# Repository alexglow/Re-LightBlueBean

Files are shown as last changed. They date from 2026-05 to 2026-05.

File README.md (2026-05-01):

# Re-LightBlueBean
Reviving [PunchThrough Design](https://punchthrough.com)'s [LightBlue Bean](https://punchthrough.com/bean), after the shutdown. Because this beautiful little Bluetooth board deserves to live :D  

I've written up a tutorial for Mac users on my [website page](https://alexglow.notion.site/Beanie-Bots-19a5bc4fe798809aa190db6e0d67d61d?source=copy_link), which will likely update far more often than this repo. As of May '26, feel free to hit me up on [Mastodon](https://chaos.social/@alexglow) or [Bluesky](https://bsky.app/profile/alexglow.bsky.social) for updates.

I'm especially interested in backing up the Bean+ files, if anyone has them – since I was mostly interested in the original Bean.

## Hardware files
When PunchThrough discontinued the LightBlue Bean and Bean+, they open-sourced the files. What you see here is the ones I grabbed for the former, as well as a file with some of their notes.

## Code examples
Unless otherwise noted, examples were written by the PunchThrough team and are in the public domain. This info should be in the files, but I'm trying to get some basic material up immediately, and then I'll double-check.

I'm planning to upload two versions: a backup of their originals, and new versions I've been able to compile and upload in 2026 (using the PlatformIO plugin in VSCode).

## Other resources
* Archived examples page: https://web.archive.org/web/20151220051847/http://legacy.punchthrough.com/bean/examples
* Archived getting-started page: https://web.archive.org/web/20160920033849/http://punchthrough.com/bean/guides/getting-started/intro
* My ancient tutorial on Hackster.io (2016): https://www.hackster.io/glowascii/lightblue-bean-arduino-basics-de7a94
* More LightBlue Bean & Bean+ projects on Hackster.io: https://www.hackster.io/punchthrough/projects

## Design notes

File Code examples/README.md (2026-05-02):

# Code examples for LightBlue Bean

### Tested LightBlue Bean demos
Some examples I've cobbled together from other sources – including my own old Hackster project(s) and example Arduino code.

### Original PunchThrough demos
Pulled from the original PunchThrough site (via the Internet Archive). I added the public-domain header, along with the exact URL each was pulled from. These will probably work, using [this updated process](https://alexglow.notion.site/Beanie-Bots-19a5bc4fe798809aa190db6e0d67d61d?source=copy_link), as long as you add **#include <Arduino.h>** at the top.

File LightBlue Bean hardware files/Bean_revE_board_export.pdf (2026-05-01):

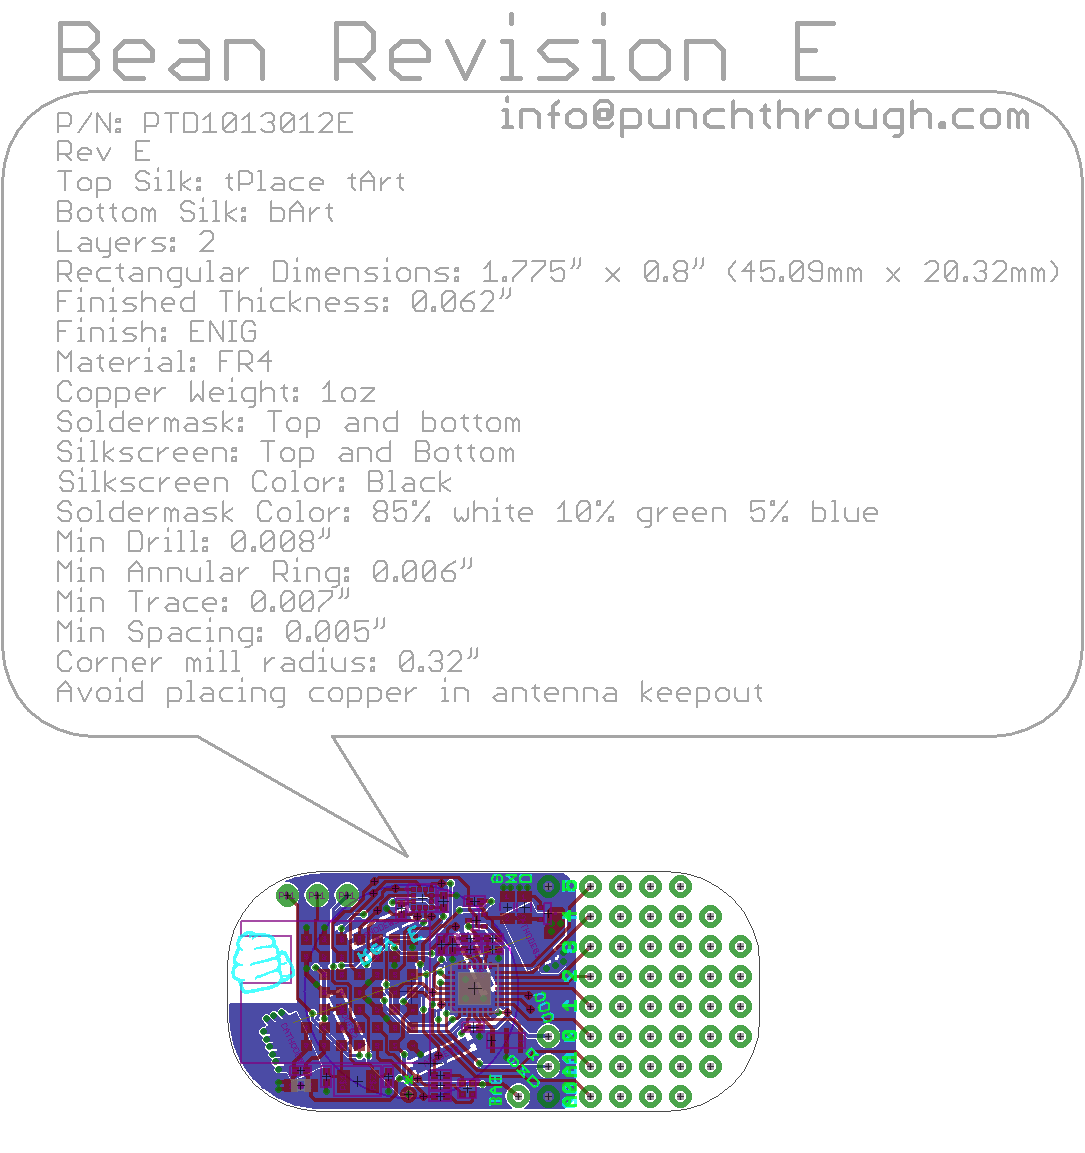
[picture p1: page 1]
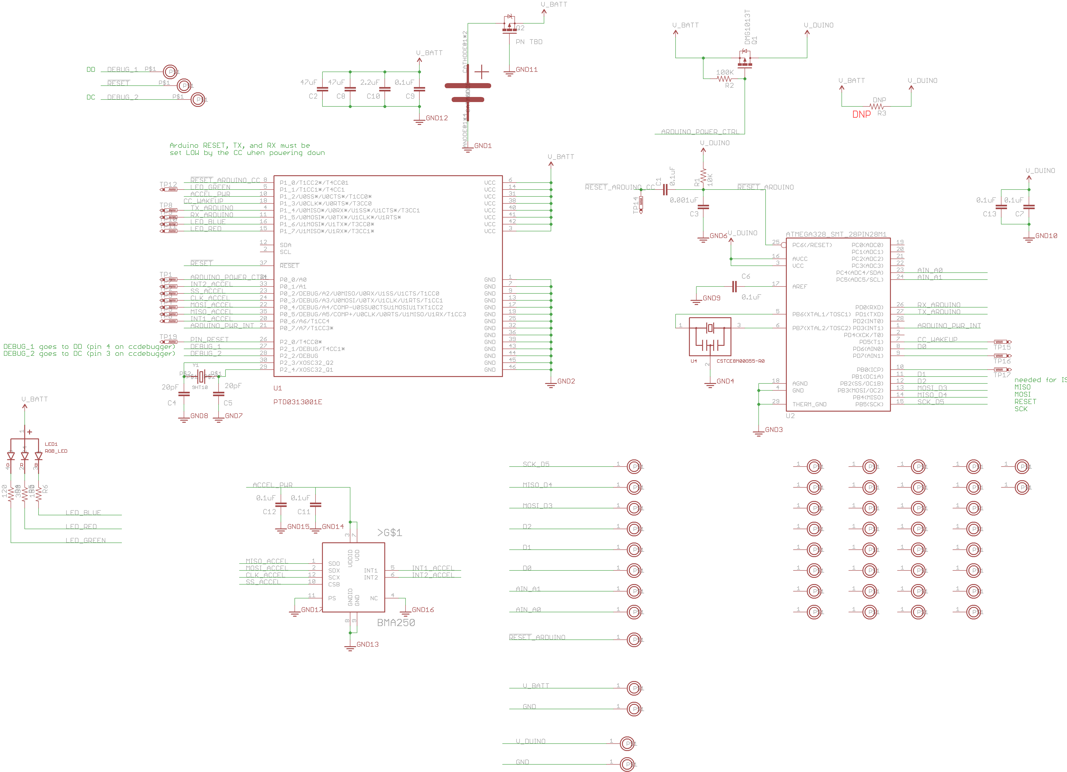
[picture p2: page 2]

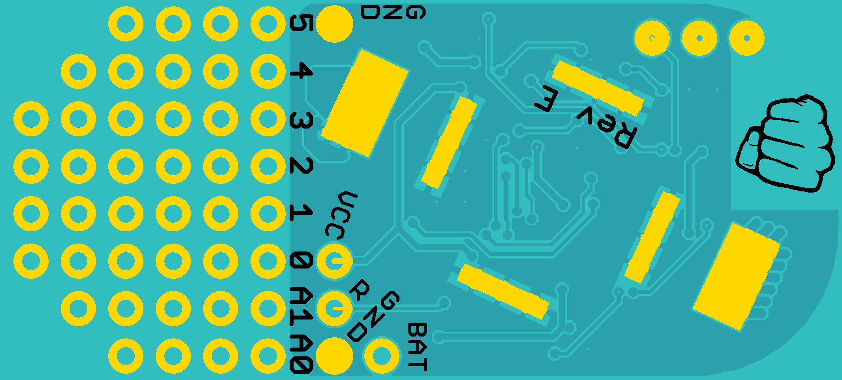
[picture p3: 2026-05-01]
LightBlue Bean hardware files/LightBlue Bean Rev E Board Files and 3D Model/3D Model/BEAN_MODEL_REVE_1.1.0/eagleUp_Bean_revE_bottom_board.png

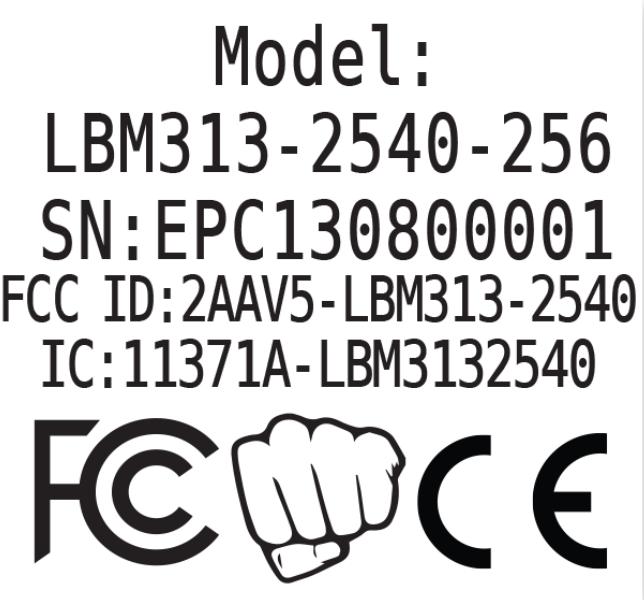
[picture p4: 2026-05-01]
LightBlue Bean hardware files/LightBlue Bean Rev E Board Files and 3D Model/3D Model/BEAN_MODEL_REVE_1.1.0/texture.png

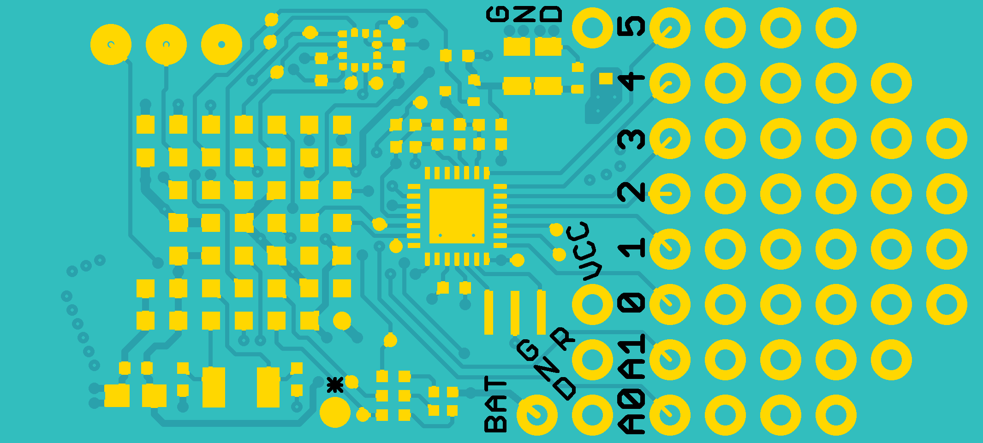
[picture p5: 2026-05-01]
LightBlue Bean hardware files/LightBlue Bean Rev E Board Files and 3D Model/3D Model/BEAN_MODEL_REVE_1.1.0/eagleUp_Bean_revE_top_board.png

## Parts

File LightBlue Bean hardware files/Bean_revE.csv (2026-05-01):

Part | Value | Device | Package | Description | TP_SIGNAL_NAME
C1 | 0.1uF | CAPACITOR_CERAMIC | 0402
C2 | 47uF | CAP0805 | 0805 | Capacitor
C3 | 0.001uF | CAPACITOR_CERAMIC | 0402
C4 | 20pF | CAPACITOR_CERAMIC | 0402
C5 | 20pF | CAPACITOR_CERAMIC | 0402
C6 | 0.1uF | CAPACITOR_CERAMIC | 0402
C7 | 0.1uF | CAPACITOR_CERAMIC | 0402
C8 | 47uF | CAP0805 | 0805 | Capacitor
C9 | 0.1uF | CAPACITOR_CERAMIC | 0402
C10 | 2.2uF | CAP0603-CAP | 0603-CAP | Capacitor
C11 | 0.1uF | CAPACITOR_CERAMIC | 0402
C12 | 0.1uF | CAPACITOR_CERAMIC | 0402
C13 | 0.1uF | CAPACITOR_CERAMIC | 0402
CN_BATT | CR20324_ELEVATED_PADS | CR20324_ELEVATED_PADS | BK-912-ALT
LED1 | RGB_LED | RGB_LED | SML-LX0404SIUPGUSB
Q1 | DMG1013T | MOSFET-PCHANNEL | SOT523 | Generic PMOSFET
Q2 | PN TBD | MOSFET-PCHANNEL | SOT523 | Generic PMOSFET
R1 | 10K | RESISTOR | 0402
R2 | 100K | RESISTOR | 0402
R3 | DNP | RESISTOR | 0402
R4 | 120 | RESISTOR | 0402
R5 | 390 | RESISTOR | 0402
R6 | 150 | RESISTOR | 0402
TP1 | PTR1TP06R | PTR1TP06R | TP06R | TEST PIN
TP2 | PTR1TP06R | PTR1TP06R | TP06R | TEST PIN
TP3 | PTR1TP06R | PTR1TP06R | TP06R | TEST PIN
TP4 | PTR1TP06R | PTR1TP06R | TP06R | TEST PIN
TP5 | PTR1TP06R | PTR1TP06R | TP06R | TEST PIN
TP6 | PTR1TP06R | PTR1TP06R | TP06R | TEST PIN
TP7 | PTR1TP06R | PTR1TP06R | TP06R | TEST PIN
TP8 | PTR1TP06R | PTR1TP06R | TP06R | TEST PIN
TP9 | PTR1TP06R | PTR1TP06R | TP06R | TEST PIN
TP10 | PTR1TP06R | PTR1TP06R | TP06R | TEST PIN
TP11 | PTR1TP06R | PTR1TP06R | TP06R | TEST PIN
TP12 | PTR1TP06R | PTR1TP06R | TP06R | TEST PIN
TP14 | PTR1TP06R | PTR1TP06R | TP06R | TEST PIN
TP15 | PTR1TP06R | PTR1TP06R | TP06R | TEST PIN
TP16 | PTR1TP06R | PTR1TP06R | TP06R | TEST PIN
TP17 | PTR1TP06R | PTR1TP06R | TP06R | TEST PIN
TP19 | PTR1TP14R | PTR1TP14R | TP14R | TEST PIN
U$1 | PROTO_POINT | PROTO_POINT | 1X01
U$3 | PROTO_POINT | PROTO_POINT | 1X01
U$4 | PROTO_POINT | PROTO_POINT | 1X01
U$5 | PROTO_POINT | PROTO_POINT | 1X01
U$6 | PROTO_POINT | PROTO_POINT | 1X01
U$7 | PROTO_POINT | PROTO_POINT | 1X01
U$8 | PROTO_POINT | PROTO_POINT | 1X01
U$9 | PROTO_POINT | PROTO_POINT | 1X01
U$10 | PROTO_POINT | PROTO_POINT | 1X01
U$11 | PROTO_POINT | PROTO_POINT | 1X01
U$12 | PROTO_POINT | PROTO_POINT | 1X01
U$13 | PROTO_POINT | PROTO_POINT | 1X01
U$14 | PROTO_POINT | PROTO_POINT | 1X01
U$15 | PROTO_POINT | PROTO_POINT | 1X01
U$16 | PROTO_POINT | PROTO_POINT | 1X01
U$17 | PROTO_POINT | PROTO_POINT | 1X01
U$18 | PROTO_POINT | PROTO_POINT | 1X01
U$19 | PROTO_POINT | PROTO_POINT | 1X01
U$20 | PROTO_POINT | PROTO_POINT | 1X01
U$21 | PROTO_POINT | PROTO_POINT | 1X01
U$22 | PROTO_POINT | PROTO_POINT | 1X01
U$23 | PROTO_POINT | PROTO_POINT | 1X01
U$24 | PROTO_POINT | PROTO_POINT | 1X01
U$25 | PROTO_POINT | PROTO_POINT | 1X01
U$26 | PROTO_POINT | PROTO_POINT | 1X01
U$27 | PROTO_POINT | PROTO_POINT | 1X01
U$28 | PROTO_POINT | PROTO_POINT | 1X01
U$29 | PROTO_POINT | PROTO_POINT | 1X01
U$30 | PROTO_POINT | PROTO_POINT | 1X01
U$31 | PROTO_POINT | PROTO_POINT | 1X01
U$32 | PROTO_POINT | PROTO_POINT | 1X01
U$33 | PROTO_POINT | PROTO_POINT | 1X01
U$34 | PROTO_POINT | PROTO_POINT | 1X01
U$35 | PROTO_POINT | PROTO_POINT | 1X01
U$36 | PROTO_POINT | PROTO_POINT | 1X01
U$37 | PROTO_POINT | PROTO_POINT | 1X01
U$38 | PROTO_POINT | PROTO_POINT | 1X01
U$39 | PROTO_POINT | PROTO_POINT | 1X01
U$40 | PROTO_POINT | PROTO_POINT | 1X01
U$41 | PROTO_POINT | PROTO_POINT | 1X01
U$42 | PROTO_POINT | PROTO_POINT | 1X01
U$43 | PROTO_POINT | PROTO_POINT | 1X01
U$44 | PROTO_POINT | PROTO_POINT | 1X01
U$45 | PROTO_POINT | PROTO_POINT | 1X01
U$46 | PROTO_POINT | PROTO_POINT | 1X01
U$49 | BEAN_PROGRAM_PIN | BEAN_PROGRAM_PIN | BEAN_PROGAM_PIN
U$50 | BEAN_PROGRAM_PIN | BEAN_PROGRAM_PIN | BEAN_PROGAM_PIN
U$51 | BEAN_PROGRAM_PIN | BEAN_PROGRAM_PIN | BEAN_PROGAM_PIN
U$52 | PROTO_POINT | PROTO_POINT | 1X01
U$53 | PROTO_POINT | PROTO_POINT | 1X01
U1 | PTD0313001E | PTD0313001E | PTD0313001E
U2 | ATMEGA328_SMT_28PIN28M1 | ATMEGA328_SMT_28PIN28M1 | QFN-28-4X4
U3 | BMA250 | BMA250 | BMA250 | Digital Accelerometer
U4 | CSTCE8M00G55-R0 | RESONATOR_3PIN | CSTCE_G_3PIN_XTAL
Y1 | 9HT10 | 9HT10 | 9HT10

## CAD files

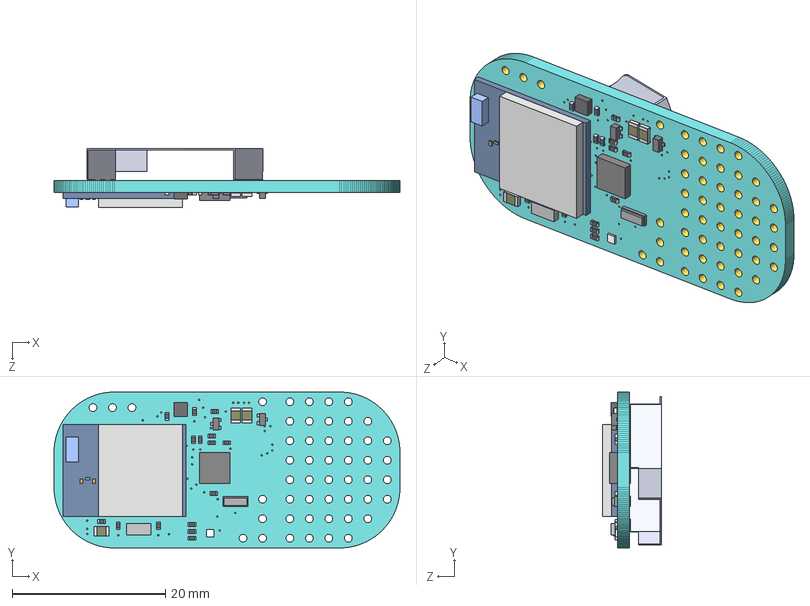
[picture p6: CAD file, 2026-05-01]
LightBlue Bean hardware files/LightBlue Bean Rev E Board Files and 3D Model/3D Model/BEAN_MODEL_REVE_1.1.0.STEP
45.1 x 20.3 x 7.72 mm
Board
RES0402 x 15
RES0805 x 3
Board_2
Extruded
Extruded_2 x 7
Extruded_3 x 15
Extruded_4 x 7
Extruded_5 x 9
Extruded_6
Extruded_7
Extruded_8
Extruded_9
Extruded_10
Extruded_11 x 2
Extruded_12 x 6
Extruded_13
Extruded_14
Extruded_15
Extruded_16
Extruded_17
Extruded_18
BK-912

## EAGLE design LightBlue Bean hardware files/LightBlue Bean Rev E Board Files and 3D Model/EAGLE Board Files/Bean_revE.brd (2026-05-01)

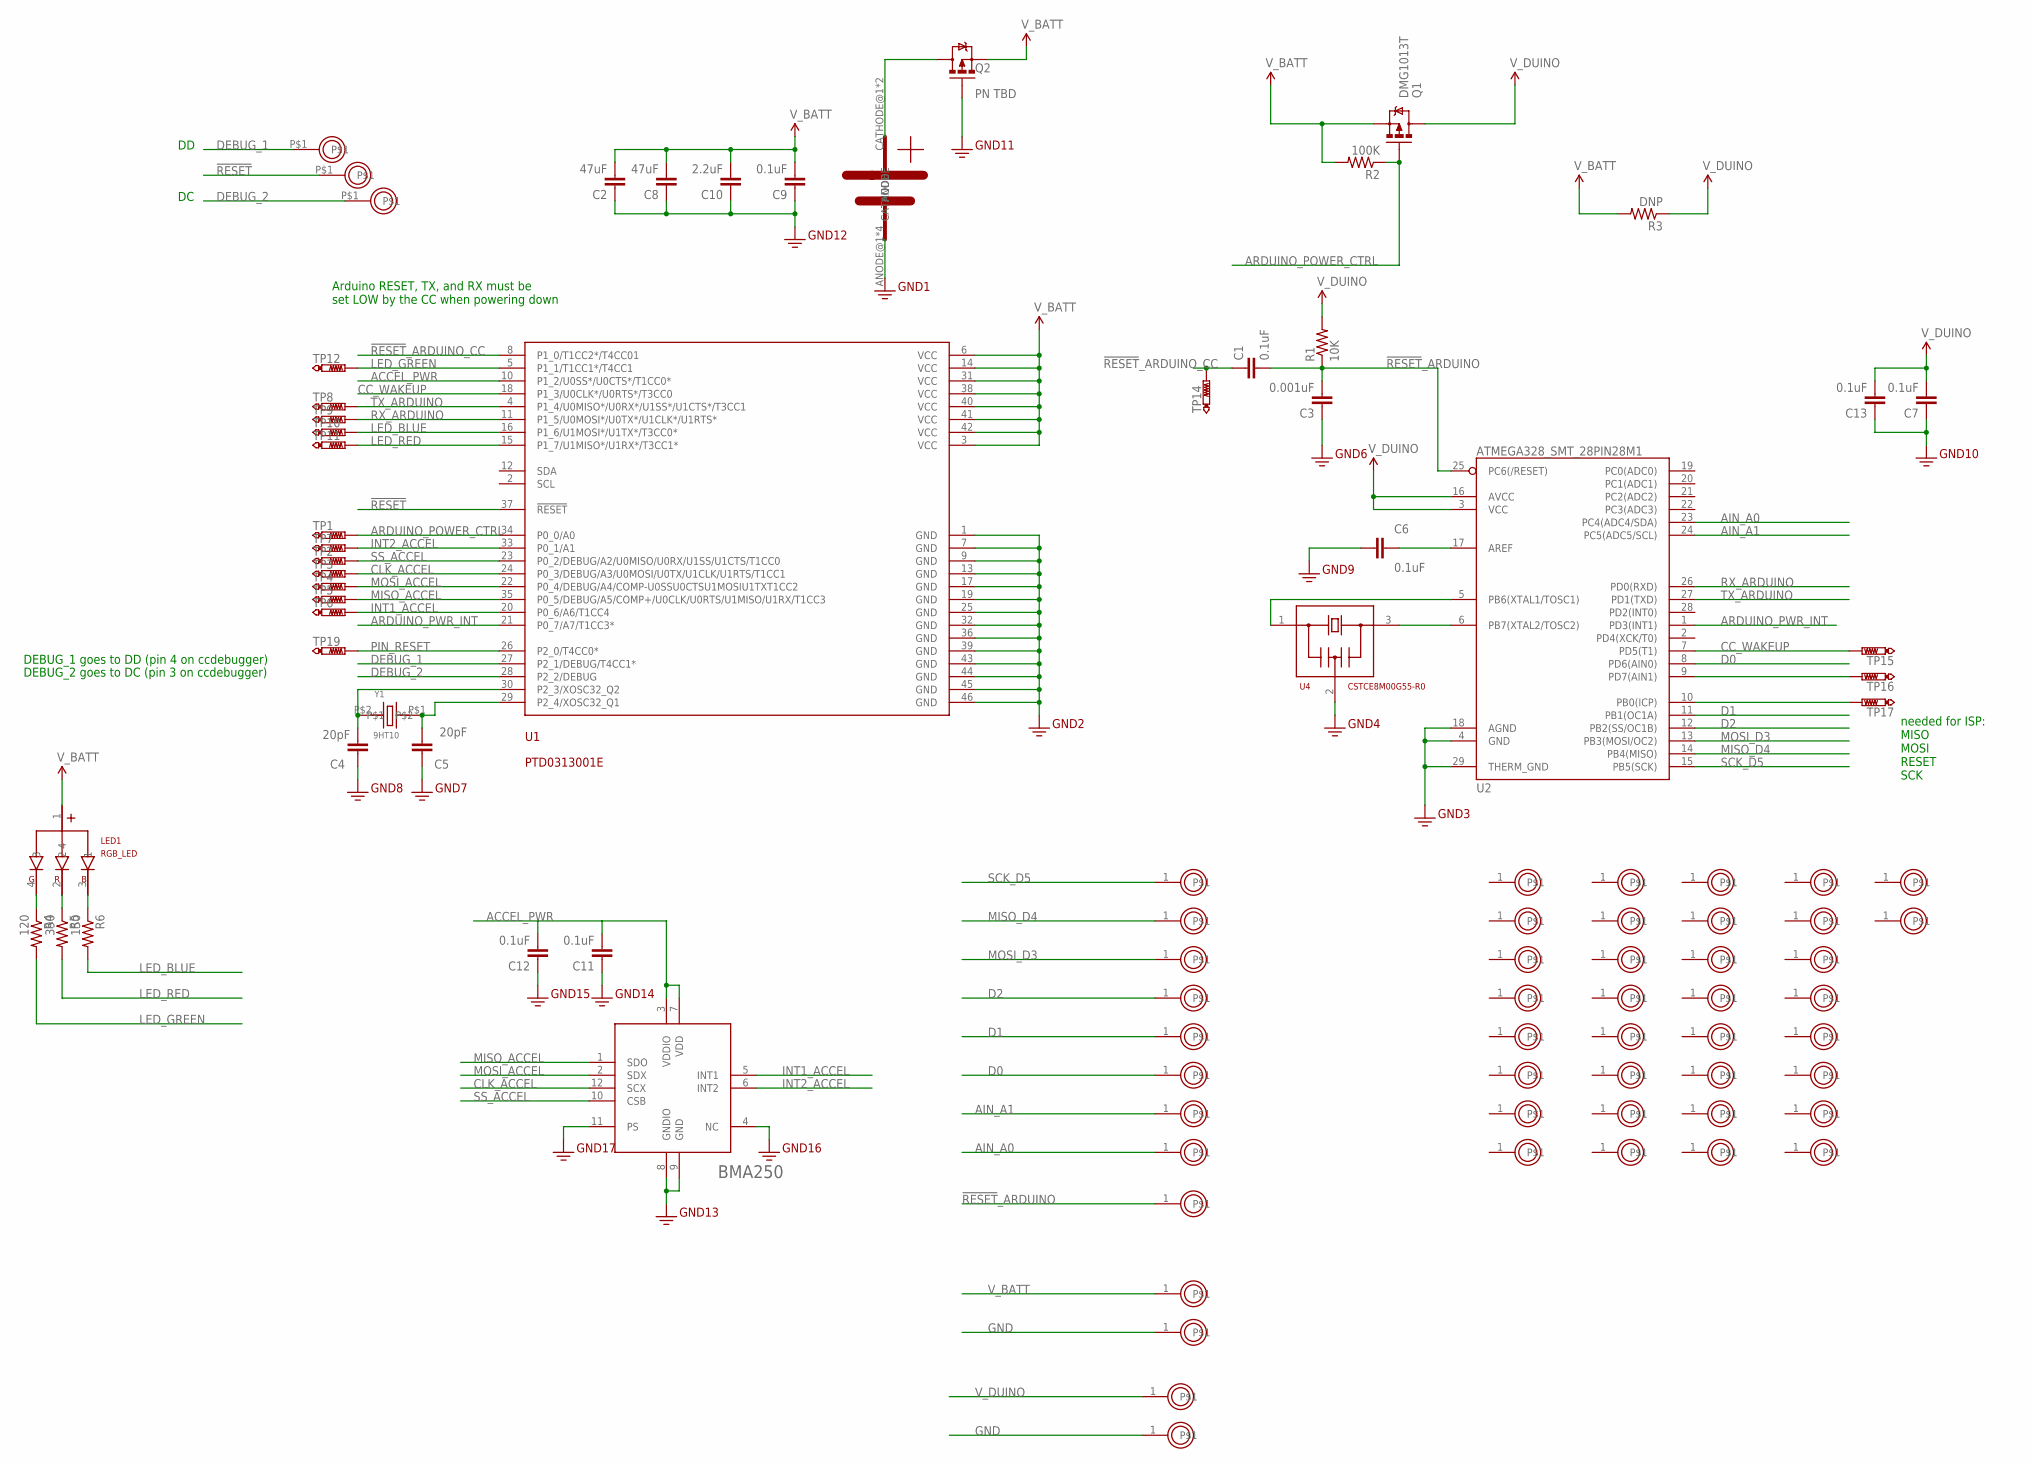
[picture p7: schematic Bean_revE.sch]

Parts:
C1, C6, C7, C9, C11, C12, C13: 0.1uF; 0402
C2, C8: 47uF; 0805
C3: 0.001uF; 0402
C4, C5: 20pF; 0402
C10: 2.2uF; 0603-CAP
CN_BATT: CR20324_ELEVATED_PADS; BK-912-ALT
LED1: RGB_LED; SML-LX0404SIUPGUSB
Q1: DMG1013T; SOT523
Q2: PN TBD; SOT523
R1: 10K; 0402
R2: 100K; 0402
R3: DNP; 0402
R4: 120; 0402
R5: 390; 0402
R6: 150; 0402
TP1, TP2, TP3, TP4, TP5, TP6, TP7, TP8, TP9, TP10, TP11, TP12, TP14, TP15, TP16, TP17: PTR1TP06R; TP06R
TP19: PTR1TP14R; TP14R
U1: PTD0313001E
U2: ATMEGA328_SMT_28PIN28M1; QFN-28-4X4
U3: BMA250
U4: CSTCE8M00G55-R0; CSTCE_G_3PIN_XTAL
U$1, U$3, U$4, U$5, U$6, U$7, U$8, U$9, U$10, U$11, U$12, U$13, U$14, U$15, U$16, U$17, U$18, U$19, U$20, U$21, U$22, U$23, U$24, U$25, U$26, U$27, U$28, U$29, U$30, U$31, U$32, U$33, U$34, U$35, U$36, U$37, U$38, U$39, U$40, U$41, U$42, U$43, U$44, U$45, U$46, U$52, U$53: PROTO_POINT; 1X01
U$49, U$50, U$51: BEAN_PROGRAM_PIN; BEAN_PROGAM_PIN
Y1: 9HT10

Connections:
!RESET!: U1.37 (!RESET!), U$50.P$1
!RESET!_ARDUINO: C1.P$2 (2), C3.P$2 (2), R1.P$1 (1), U2.25 (PC6(/RESET)), U$46.1
!RESET!_ARDUINO_CC: C1.P$1 (1), TP14.TP, U1.8 (P1_0/T1CC2*/T4CC01)
ACCEL_PWR: C11.P$2 (2), C12.P$2 (2), U1.10 (P1_2/U0SS*/U0CTS*/T1CC0*), U3.3 (VDDIO), U3.7 (VDD)
AIN_A0: U2.23 (PC4(ADC4/SDA)), U$10.1
AIN_A1: U2.24 (PC5(ADC5/SCL)), U$9.1
ARDUINO_POWER_CTRL: Q1.G, R2.P$1 (1), TP1.TP, U1.34 (P0_0/A0)
ARDUINO_PWR_INT: U1.21 (P0_7/A7/T1CC3*), U2.1 (PD3(INT1))
CC_WAKEUP: TP15.TP, U1.18 (P1_3/U0CLK*/U0RTS*/T3CC0), U2.7 (PD5(T1))
CLK_ACCEL: TP3.TP, U1.24 (P0_3/DEBUG/A3/U0MOSI/U0TX/U1CLK/U1RTS/T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), U3.12 (SCX)
D0: U2.8 (PD6(AIN0)), U$8.1
D1: U2.11 (PB1(OC1A)), U$7.1
D2: U2.12 (PB2(SS/OC1B)), U$6.1
DEBUG_1: U1.27 (P2_1/DEBUG/T4CC1*), U$51.P$1
DEBUG_2: U1.28 (P2_2/DEBUG), U$49.P$1
GND: C2.1, C3.P$1 (1), C4.P$1 (1), C5.P$1 (1), C6.P$1 (1), C7.P$1 (1), C8.1, C9.P$1 (1), C10.1, C11.P$1 (1), C12.P$1 (1), C13.P$1 (1), CN_BATT.ANODE@1 (ANODE), CN_BATT.ANODE@2 (ANODE), CN_BATT.ANODE@3 (ANODE), CN_BATT.ANODE@4 (ANODE), Q2.G, U1.1 (GND), U1.7 (GND), U1.9 (GND), U1.13 (GND), U1.17 (GND), U1.19 (GND), U1.25 (GND), U1.32 (GND), U1.36 (GND), U1.39 (GND), U1.43 (GND), U1.44 (GND), U1.45 (GND), U1.46 (GND), U2.4 (GND), U2.18 (AGND), U2.29 (THERM_GND), U3.4 (NC), U3.8 (GNDIO), U3.9 (GND), U3.11 (PS), U4.2, U$45.1, U$53.1
INT1_ACCEL: TP6.TP, U1.20 (P0_6/A6/T1CC4), U3.5 (INT1)
INT2_ACCEL: TP7.TP, U1.33 (P0_1/A1), U3.6 (INT2)
LED_BLUE: R6.P$2 (2), TP10.TP, U1.16 (P1_6/U1MOSI*/U1TX*/T3CC0*)
LED_GREEN: R4.P$2 (2), TP12.TP, U1.5 (P1_1/T1CC1*/T4CC1)
LED_RED: R5.P$2 (2), TP11.TP, U1.15 (P1_7/U1MISO*/U1RX*/T3CC1*)
MISO_ACCEL: TP5.TP, U1.35 (P0_5/DEBUG/A5/COMP+/U0CLK/U0RTS/U1MISO/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), U3.1 (SDO)
MISO_D4: U2.14 (PB4(MISO)), U$4.1
MOSI_ACCEL: TP4.TP, U1.22 (P0_4/DEBUG/A4/COMP-U0SSU0CTSU1MOSIU1TXT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), U3.2 (SDX)
MOSI_D3: U2.13 (PB3(MOSI/OC2)), U$5.1
unnamed: U2.5 (PB6(XTAL1/TOSC1)), U4.1
unnamed: U2.6 (PB7(XTAL2/TOSC2)), U4.3
unnamed: C4.P$2 (2), U1.30 (P2_3/XOSC32_Q2), Y1.P$2
unnamed: C5.P$2 (2), U1.29 (P2_4/XOSC32_Q1), Y1.P$1
unnamed: C6.P$2 (2), U2.17 (AREF)
unnamed: LED1.4 (3), R4.P$1 (1)
unnamed: LED1.2, R5.P$1 (1)
unnamed: LED1.3 (1), R6.P$1 (1)
PB0: TP17.TP, U2.10 (PB0(ICP))
PD7: TP16.TP, U2.9 (PD7(AIN1))
PIN_RESET: TP19.TP, U1.26 (P2_0/T4CC0*)
PRE_V_BATT: CN_BATT.CATHODE@1 (CATHODE), CN_BATT.CATHODE@2 (CATHODE), Q2.D
RX_ARDUINO: TP9.TP, U1.11 (P1_5/U0MOSI*/U0TX*/U1CLK*/U1RTS*), U2.26 (PD0(RXD))
SCK_D5: U2.15 (PB5(SCK)), U$3.1
SS_ACCEL: TP2.TP, U1.23 (P0_2/DEBUG/A2/U0MISO/U0RX/U1SS/U1CTS/T1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), U3.10 (CSB)
TX_ARDUINO: TP8.TP, U1.4 (P1_4/U0MISO*/U0RX*/U1SS*/U1CTS*/T3CC1), U2.27 (PD1(TXD))
V_BATT: C2.2, C8.2, C9.P$2 (2), C10.2, LED1.1 (4), Q1.S, Q2.S, R2.P$2 (2), R3.P$2 (2), U1.3 (VCC), U1.6 (VCC), U1.14 (VCC), U1.31 (VCC), U1.38 (VCC), U1.40 (VCC), U1.41 (VCC), U1.42 (VCC), U$52.1
V_DUINO: C7.P$2 (2), C13.P$2 (2), Q1.D, R1.P$2 (2), R3.P$1 (1), U2.3 (VCC), U2.16 (AVCC), U$1.1

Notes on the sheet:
needed for ISP: MISO MOSI RESET SCK
DEBUG_2 goes to DC (pin 3 on ccdebugger)
DEBUG_1 goes to DD (pin 4 on ccdebugger)
Arduino RESET, TX, and RX must be set LOW by the CC when powering down

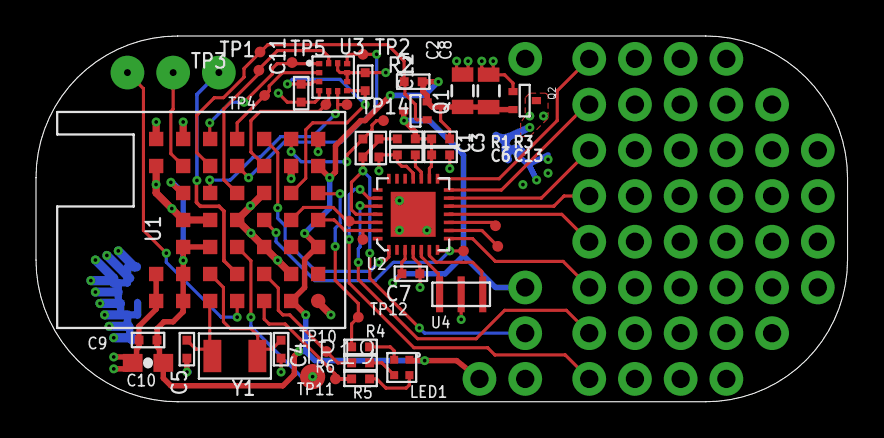
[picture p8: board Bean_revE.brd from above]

Board: 2 copper layers, 45.1 x 20.3 mm, 95 parts (1 on the bottom side), 43 nets.

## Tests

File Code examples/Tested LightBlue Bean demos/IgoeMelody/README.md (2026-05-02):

# IgoeMelody for LightBlue Bean

Plays a short melody when the LightBlue Bean is powered on.

Adapted from Tom Igoe's example for the Arduino Tone library: https://docs.arduino.cc/built-in-examples/digital/toneMelody

Place the **pitches.h** file in the same directory as **main.cpp**

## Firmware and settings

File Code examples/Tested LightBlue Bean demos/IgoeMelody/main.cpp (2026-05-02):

/*
  Melody

  Plays a melody

  circuit:
  - 8 ohm speaker on digital pin 0

  created 21 Jan 2010
  modified 30 Aug 2011
  by Tom Igoe

  Updated for LightBlue Bean: 1 May 2026
  by Alex Glow

  This example code is in the public domain.

  https://www.arduino.cc/en/Tutorial/BuiltInExamples/toneMelody
*/

#include <Arduino.h>
#include "pitches.h"

int speaker = 0;

// notes in the melody:
int melody[] = {
  NOTE_C4, NOTE_G3, NOTE_G3, NOTE_A3, NOTE_G3, 0, NOTE_B3, NOTE_C4
};

// note durations: 4 = quarter note, 8 = eighth note, etc.:
int noteDurations[] = {
  4, 8, 8, 4, 4, 4, 4, 4
};

void setup() {
  // iterate over the notes of the melody:
  for (int thisNote = 0; thisNote < 8; thisNote++) {

    // to calculate the note duration, take one second divided by the note type.
    //e.g. quarter note = 1000 / 4, eighth note = 1000/8, etc.
    int noteDuration = 1000 / noteDurations[thisNote];
    tone(speaker, melody[thisNote], noteDuration);

    // to distinguish the notes, set a minimum time between them.
    // the note's duration + 30% seems to work well:
    int pauseBetweenNotes = noteDuration * 1.30;
    delay(pauseBetweenNotes);
    // stop the tone playing:
    noTone(speaker);
  }
}

void loop() {
  // no need to repeat the melody.
}

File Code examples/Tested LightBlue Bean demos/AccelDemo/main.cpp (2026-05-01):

/* 
  This sketch reads the acceleration from the Bean's on-board 
  accelerometer and displays it on the Bean's LED.
    
  This example code is in the public domain.
*/

#include <Arduino.h>

void setup() {
  // Optional: Use Bean.setAccelerationRange() to set the sensitivity 
  // to something other than the default of ±2g.
}

void loop() {
  // Get the current acceleration with range of ±2g, 
  // and a conversion of 3.91×10-3 g/unit or 0.03834(m/s^2)/units. 
  AccelerationReading accel = Bean.getAcceleration();

  // Update LED color
  uint16_t r = (abs(accel.xAxis)) / 4;
  uint16_t g = (abs(accel.yAxis)) / 4;
  uint16_t b = (abs(accel.zAxis)) / 4;
  Bean.setLed((uint8_t)r,(uint8_t)g,(uint8_t)b);

  Bean.sleep(50);
}

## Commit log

2026-05-01 Adding hardware files & first code example
    [BEAN_MODEL_REVE_1.1.0.STEP, Bean_revE.brd, Bean_revE.csv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]
2026-05-02 Add more code examples
    Add and organize more code examples – including ones pulled from the original PunchThrough site (via the Internet Archive), and some I've cobbled together from other sources.

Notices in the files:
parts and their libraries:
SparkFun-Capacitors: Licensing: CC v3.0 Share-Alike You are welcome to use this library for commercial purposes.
